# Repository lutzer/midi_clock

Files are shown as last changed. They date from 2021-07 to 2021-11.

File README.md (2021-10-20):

# Midi Clock

## Requirements

* install rust
  * run `curl --proto '=https' --tlsv1.2 -sSf https://sh.rustup.rs | sh` to install rust toolchain
  * use nightly toolchain: `rustup default nightly` (for heap allocator)
  * install target `rustup target install thumbv7m-none-eabi`
  * install cargo-edit `cargo install cargo-edit`, it allows to add dependencies with `cargo add <package>`

* install flash toolchain
  * install stlink on mac with `brew install stlink`
  * install *binutils-arm-none-eabi* with `brew tap PX4/homebrew-px4; brew install gcc-arm-none-eabi`

## Connect Board

* disconnect external power supply
* connect programmer *ST-Link V2* to programming pins of blue pill. Connect pins *SWDIO, GND, SWCLK, and 3.3V and RST to pin R*
* check if programmer is avalaible with `st-info --probe`

## Flash Chip

* run `./flash`
* compile with features with `./flash "feature1,feature2,..."`

## Debugging

* for debugging connect serial adapter, see in [docs/hardware.md](docs/hardware.md)
* flash chip with debug feature: `./flash debug`
* see debugging output with `screen /dev/tty.<adapter> 115200`, (Ctrl+A, K to close monitor)
* for analyzing the timings of the midi clock see [tools/clock_test/README.md](tools/clock_test/README.md)

## Links

* Midi specifications: https://www.midi.org/specifications-old/item/table-1-summary-of-midi-message
* STM32f103 Reference Manual: https://www.st.com//content/ccc/resource/technical/document/reference_manual/59/b9/ba/7f/11/af/43/d5/CD00171190.pdf/files/CD00171190.pdf/jcr:content/translations/en.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
* LCD 0802A: http://www.farnell.com/datasheets/50552.pdf
* Timer registers for stm32f103: https://docs.rs/stm32f1/0.14.0/stm32f1/stm32f103/tim2/index.html

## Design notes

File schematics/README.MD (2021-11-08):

# Midi Clock Schematics

## Setup
* copy libraries from libraries folder to eagle libraries folder
* copy schematics to eagle project folder
* open project
* activate libraries with right click and use in library manager -> use library

## BOM

## PCB Specs

* drill whole sice 0.2mm - 6.3mm
* via size: hole: 0.2mm, copper ring: 0.4mm
* plated hole size: 0.2-6.35
* min clearences
  * hole to hole: 0.5mm
  * via to via: 0.254mm
  * pad to pad with hole: 0.5mm
  * pth to track: 0.33
  * pad to track: 0.2
  * trace width: minimum 0.2mm
  * spacing: 0.2mm

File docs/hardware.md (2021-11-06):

# Hardware

## Bluepill pinout

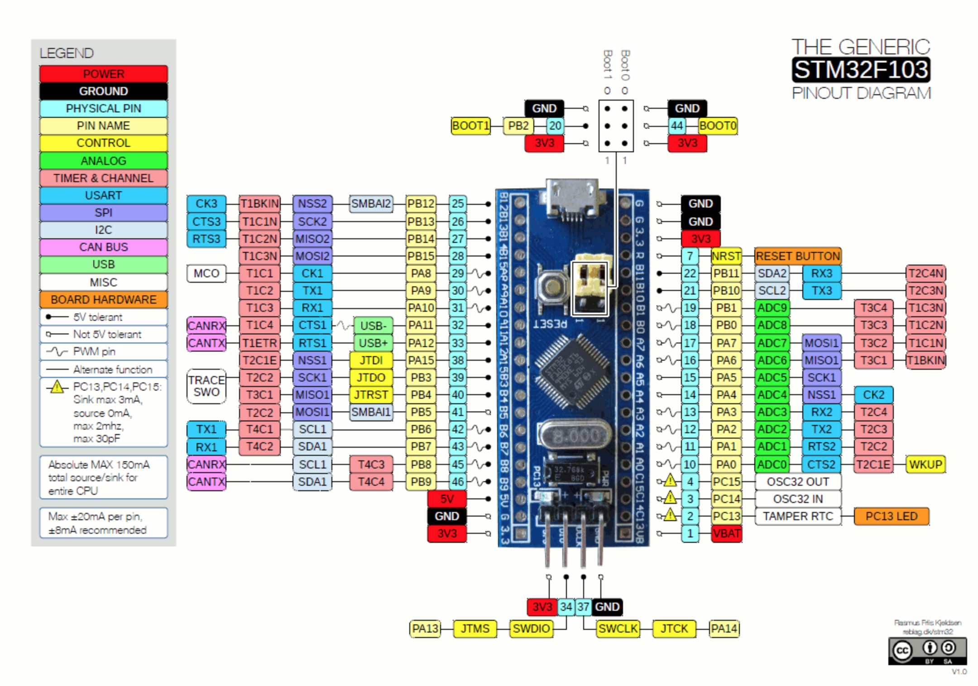
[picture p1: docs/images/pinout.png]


## Connections

| Pin  | Connection |
| ---- | --- |
| PA9  | Debug TX1 / MIDI Out1+2 |
| PA10 | Debug RX1 / MIDI IN |
| PB12 | Button1 		 |
| PB13 | Button2 		 |
| PA7  | Button3 		 |
| PA6  | Button4 (Enc) |
| PA0  | Enc1 |
| PA1  | Enc2 |
| PA9  | MIDI OUT1+2 (Hex Buffer1+2) |
| PB5  | TRIGGER1 (LED MIDI OUT1+2) |
| PA2 | MIDI OUT3+4 (Hex Buffer3+4) |
| PB4  | TRIGGER2 (LED MIDI OUT3+4) |
| PB0  | TRIGGER3 (Hex Buffer5) & LED3 |
| PB1  | TRIGGER4 RESET (Hex Buffer6) & LED4 |
| PA11 | USB D- |
| PA12 | USB D+ |
| PB3 |Clock In|
| PB6 |EEPROM IC SCL|
| PB7 |EEPROM IC SDA|
| PA8 |Display RS|
| PB15 |Display EN|
| PB11 |Display D4|
| PB10 |Display D5|
| PA4 |Display D6|
| PA5 |Display D7|

### Debugging with UART Adapter

Only connect TX to A9, RX to A10 and GND, no need for 3.3V connection

### HD44780 Display

datasheet st7066: https://www.sparkfun.com/datasheets/LCD/st7066.pdf
pinout: https://cdn-reichelt.de/documents/datenblatt/A500/DIPS082E.pdf

### Eeprom

datasheet 24LC64: http://ww1.microchip.com/downloads/en/devicedoc/21189f.pdf

### BOM

* Hex Buffer: 74HC 365
* Clock in: BC 635 Bipolartransistor, NPN, 45V, 1A, 0,8W, TO-92

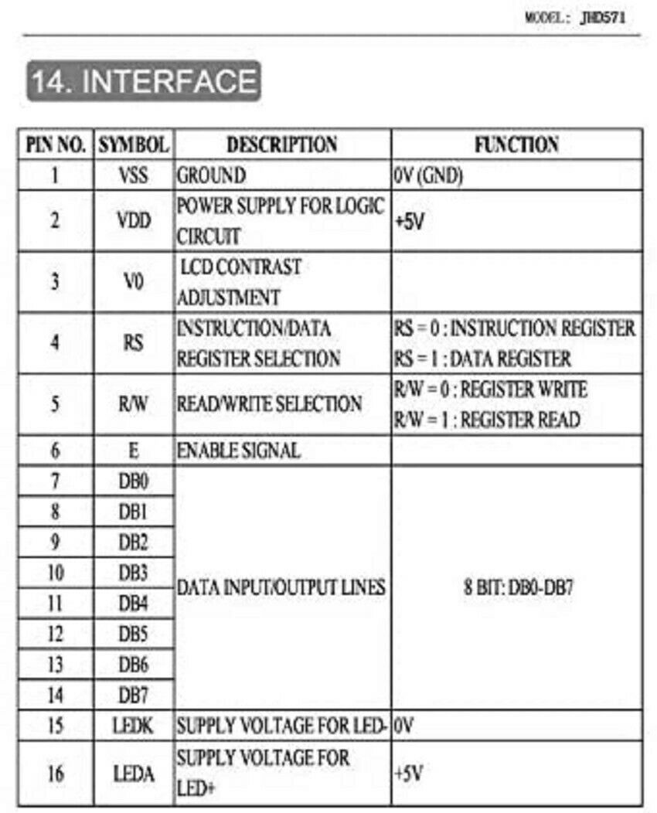
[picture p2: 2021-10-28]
docs/images/lcd_interface.jpeg

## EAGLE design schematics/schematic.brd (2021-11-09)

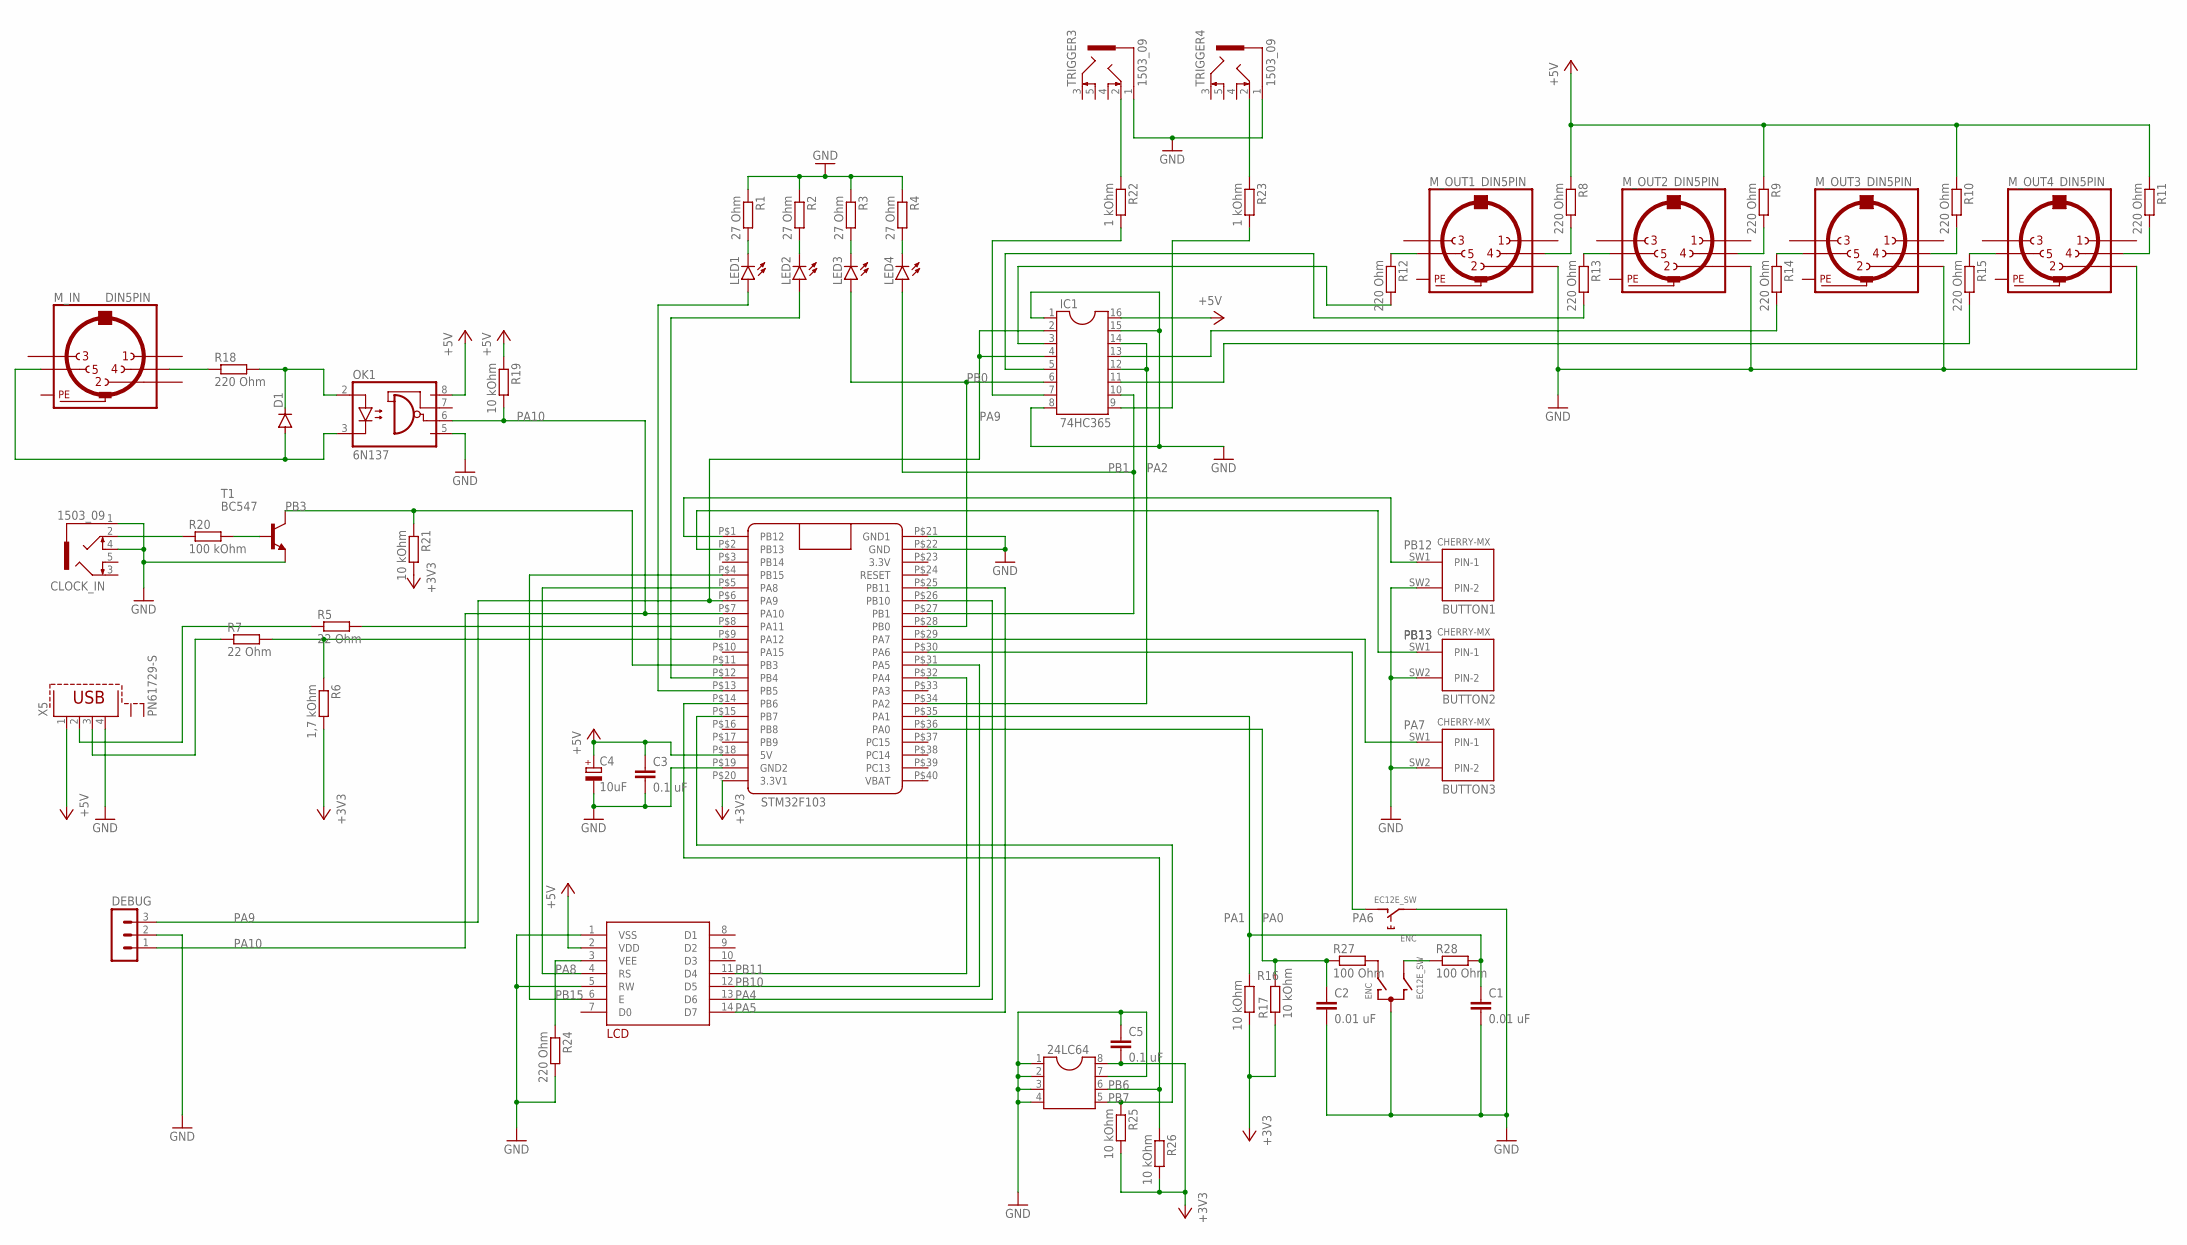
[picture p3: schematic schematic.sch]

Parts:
24LC64: DIL8; DIL08
BUTTON1, BUTTON2, BUTTON3: CHERRY-MX
C1, C2: 0.01 uF; C050-025X075
C3, C5: 0.1 uF; C050-025X075
C4: 10uF; E2,5-6
CLOCK_IN: 1503_09
D1: 1N4446; DO35-10
DEBUG: MA03-1
ENC: EC12E_SW; ALPS_EC12E_SW
IC1: 74HC365; SOCKET-16
LCD: LCD-MODUL2X8
LED1, LED2, LED3, LED4: LED3MM
M_IN: DIN5PIN; MABPM5S
M_OUT1, M_OUT2, M_OUT3, M_OUT4: DIN5PIN; MABPM5S
OK1: 6N137; DIL08
R1, R2, R3, R4: 27 Ohm; 0207/10
R5, R7: 22 Ohm; 0207/10
R6: 1,7 kOhm; 0207/10
R8, R9, R10, R11, R12, R13, R14, R15, R18, R24: 220 Ohm; 0207/10
R16, R17, R19, R21, R25, R26: 10 kOhm; 0207/10
R20: 100 kOhm; 0207/10
R22, R23: 1 kOhm; 0207/10
R27, R28: 100 Ohm; 0207/10
STM32F103: BLUE_PILL
T1: BC547; TO92
TRIGGER3, TRIGGER4: 1503_09
X5: PN61729-S

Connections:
+3V3: 24LC64.8, C5.2, R6.2, R16.2, R17.1, R21.2, R25.2, R26.2, STM32F103.P$20 (3.3V1)
+5V: C3.1, C4.+, IC1.16, LCD.2 (VDD), OK1.8 (VCC), R8.1, R9.1, R10.1, R11.1, R19.1, STM32F103.P$18 (5V), X5.1
GND: 24LC64.1, 24LC64.2, 24LC64.3, 24LC64.4, 24LC64.7, BUTTON1.SW2 (PIN-2), BUTTON2.SW2 (PIN-2), BUTTON3.SW2 (PIN-2), C1.2, C2.2, C3.2, C4.-, C5.1, CLOCK_IN.1, CLOCK_IN.4, DEBUG.2, ENC.C, ENC.E (2), IC1.1, IC1.8, IC1.15, LCD.1 (VSS), LCD.5 (RW), M_OUT1.P2 (2), M_OUT2.P2 (2), M_OUT3.P2 (2), M_OUT4.P2 (2), OK1.5 (GND), R1.1, R2.1, R3.1, R4.1, R24.2, STM32F103.P$19 (GND2), STM32F103.P$21 (GND1), STM32F103.P$22 (GND), T1.1 (E), TRIGGER3.1, TRIGGER4.1, X5.4
unnamed: R5.1, X5.2
unnamed: R5.2, STM32F103.P$8 (PA11)
unnamed: R7.1, X5.3
unnamed: LED1.K (C), R1.2
unnamed: LED2.K (C), R2.2
unnamed: LED3.K (C), R3.2
unnamed: LED4.K (C), R4.2
unnamed: R6.1, R7.2, STM32F103.P$9 (PA12)
unnamed: M_OUT1.P4 (4), R8.2
unnamed: M_OUT2.P4 (4), R9.2
unnamed: M_OUT3.P4 (4), R10.2
unnamed: M_OUT4.P4 (4), R11.2
unnamed: M_OUT1.P5 (5), R12.1
unnamed: M_OUT2.P5 (5), R13.1
unnamed: M_OUT3.P5 (5), R14.1
unnamed: M_OUT4.P5 (5), R15.1
unnamed: IC1.3, R12.2
unnamed: IC1.5, R13.2
unnamed: IC1.13, R14.2
unnamed: IC1.11, R15.2
unnamed: ENC.A, R27.2
unnamed: ENC.B, R28.1
unnamed: D1.C, OK1.2 (A), R18.2
unnamed: D1.A, M_IN.P5 (5), OK1.3 (C)
unnamed: M_IN.P4 (4), R18.1
unnamed: LCD.3 (VEE), R24.1
unnamed: CLOCK_IN.2, R20.1
unnamed: R20.2, T1.2 (B)
unnamed: R22.1, TRIGGER3.2
unnamed: IC1.7, R22.2
unnamed: R23.1, TRIGGER4.2
unnamed: IC1.9, R23.2
PA0: C2.1, R17.2, R27.1, STM32F103.P$36 (PA0)
PA1: C1.1, R16.1, R28.2, STM32F103.P$35 (PA1)
PA2: IC1.12, IC1.14, STM32F103.P$34 (PA2)
PA4: LCD.11 (D4), STM32F103.P$32 (PA4)
PA5: LCD.12 (D5), STM32F103.P$31 (PA5)
PA6: ENC.D (1), STM32F103.P$30 (PA6)
PA7: BUTTON3.SW1 (PIN-1), STM32F103.P$29 (PA7)
PA8: LCD.4 (RS), STM32F103.P$5 (PA8)
PA9: DEBUG.3, IC1.2, IC1.4, STM32F103.P$6 (PA9)
PA10: DEBUG.1, OK1.6 (VO), R19.2, STM32F103.P$7 (PA10)
PB0: IC1.6, LED3.A, STM32F103.P$28 (PB0)
PB1: IC1.10, LED4.A, STM32F103.P$27 (PB1)
PB3: R21.1, STM32F103.P$11 (PB3), T1.3 (C)
PB4: LED2.A, STM32F103.P$12 (PB4)
PB5: LED1.A, STM32F103.P$13 (PB5)
PB6: 24LC64.6, R26.1, STM32F103.P$14 (PB6)
PB7: 24LC64.5, R25.1, STM32F103.P$15 (PB7)
PB10: LCD.13 (D6), STM32F103.P$26 (PB10)
PB11: LCD.14 (D7), STM32F103.P$25 (PB11)
PB12: BUTTON1.SW1 (PIN-1), STM32F103.P$1 (PB12)
PB13: BUTTON2.SW1 (PIN-1), STM32F103.P$2 (PB13)
PB15: LCD.6 (E), STM32F103.P$4 (PB15)
PE: M_IN.PE, M_IN.PE@ (PE), M_OUT1.PE, M_OUT1.PE@ (PE), M_OUT2.PE, M_OUT2.PE@ (PE), M_OUT3.PE, M_OUT3.PE@ (PE), M_OUT4.PE, M_OUT4.PE@ (PE)

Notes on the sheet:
STM32F103

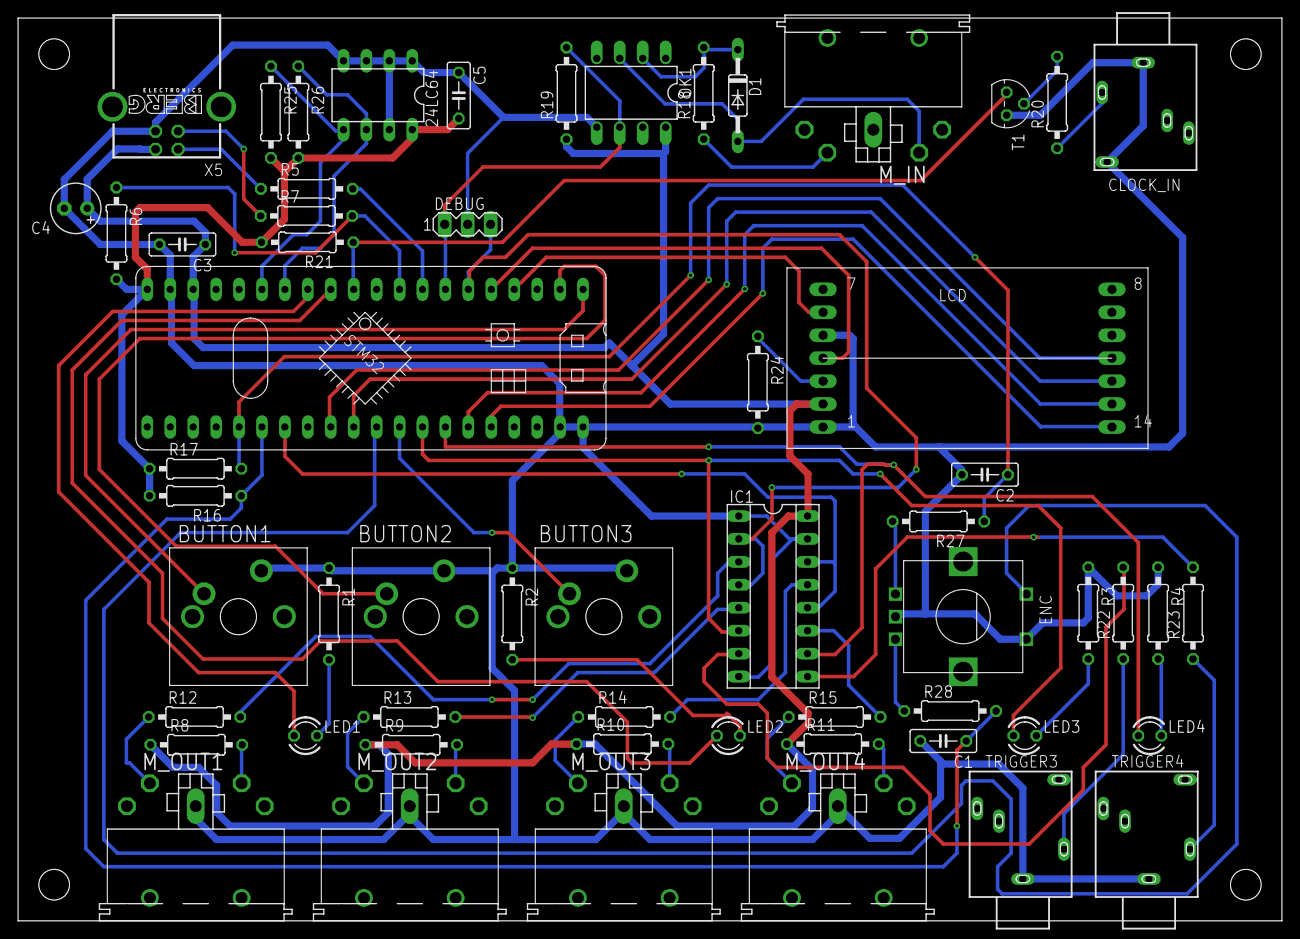
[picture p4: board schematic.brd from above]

Board: 2 copper layers, 140.0 x 100.0 mm, 58 parts (0 on the bottom side), 58 nets.

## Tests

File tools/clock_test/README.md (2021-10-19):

# Clock Analyzer

* upload clock_analyzer firmware on arduino uno
* connect the Rx port of the arduino with the Tx of the midi signal you want to analyze
* flash midi clock with `./flash clock_test`
* set serial port of arduino in *clock_analyzer.py* and run python script with: `python3 clock_analyzer.py`

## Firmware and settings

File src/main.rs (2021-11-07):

#![no_std]
#![no_main]

use cortex_m_rt::entry;
use cortex_m::interrupt;
use cortex_m::interrupt::{CriticalSection};

use core::panic::PanicInfo;

mod peripherals;
use peripherals::{Peripherals};

mod serial;
use serial::{SerialWriter};

mod buttons;
use buttons::{Buttons, BUTTON1_MASK, BUTTON2_MASK, BUTTON3_MASK, BUTTON4_MASK, buttons_on_timer_tick};

mod timers;
use timers::{Timer3};

mod debug;

mod utils;

mod encoder;
use encoder::{Encoder};

mod clock;
use clock::{Clock};

mod triggers;
use triggers::{Triggers, TRIGGER4_MASK};

mod statemachine;
use statemachine::{Statemachine, State, RunState};

mod context;
use context::{Context, CONTEXT};

mod display;
use display::{Display};

mod midi;
use midi::{MidiMessage};

mod st7066;

mod eeprom;
use eeprom::{Eeprom};

mod memory;
use memory::{Memory};

fn on_button_press(statemachine: &mut Statemachine, changes: u8, state: u8) {
  if (changes & BUTTON1_MASK) > 0 {
    statemachine.button1_pressed(changes & BUTTON1_MASK & state > 0);
  }
  if (changes & BUTTON2_MASK) > 0 {
    statemachine.button2_pressed(changes & BUTTON2_MASK & state > 0);
  }
  if (changes & BUTTON3_MASK) > 0 {
    statemachine.button3_pressed(changes & BUTTON3_MASK & state > 0);
  }
  if (changes & BUTTON4_MASK) > 0 {
    statemachine.encoder_pressed(changes & BUTTON4_MASK & state > 0);
  }
}

fn on_encoder_change(statemachine: &mut Statemachine, rotation: i16) {
  statemachine.encoder_turn(rotation);
}

fn on_state_change(state: &State, clock: &mut Clock, display: &mut Display) {
  static mut PREV_STATE : Option<State> = None;

  debug!("state change");
  debug!(*state);

  if let Some(prev_state) = unsafe { PREV_STATE } {
    // check for state changes
    if prev_state.running != state.running {
      clock.set_runstate(state.running);
      send_midi_ctrl_msg(state.running);
    }
    if prev_state.bpm != state.bpm {
      clock.set_bpm(state.bpm);
    }
    if prev_state.clock_trigger_multiplier != state.clock_trigger_multiplier {
      clock.set_trigger_multiplier(state.clock_trigger_multiplier);
    }
    if prev_state.clock_divisions[0] != state.clock_divisions[0] || prev_state.clock_divisions[1] != state.clock_divisions[1] {
      clock.set_divisions(state.clock_divisions);
    }
    if prev_state.clock_bar_length != state.clock_bar_length {
      clock.set_bar_length(state.clock_bar_length);
    } 
    if prev_state.clock_sync != state.clock_sync {
      clock.sync(state.clock_sync);
    }
    display.update(state);
  }
  unsafe { PREV_STATE = Some(*state) }
}

fn send_midi_ctrl_msg(current: RunState) {
  interrupt::free(|cs| {
    Context::get_instance(cs, &|ctx| {
      match current {
        RunState::RUNNING => { 
          ctx.serial.write(2, MidiMessage::Continue as u8).ok(); 
        },
        RunState::PAUSED => { 
          ctx.serial.write(2, MidiMessage::Stop as u8).ok(); 
        },
        RunState::STOPPING => { 
          ctx.serial.write(2, MidiMessage::Stop as u8).ok(); 
        },
        RunState::STOPPED => { 
          ctx.serial.write(2, MidiMessage::Start as u8).ok();
          ctx.triggers.fire(TRIGGER4_MASK); // send sync reset trigger
        }
      }
    });
  });
}

#[entry]
fn main() -> ! {

  // initialize peripherals
  let peripherals = Peripherals::init();

  // init eeprom memory chip
  let mut memory = Memory::new(Eeprom::new(peripherals.i2c1.unwrap()));

  // initialize statemachine and read state from memory
  let mut statemachine = Statemachine::new(memory.load_state());
  let initial_state = statemachine.get_state();

  // initializes all buttons and sets debounce timer
  let buttons = Buttons::new(peripherals.button1.unwrap(), peripherals.button2.unwrap(), 
    peripherals.button3.unwrap(), peripherals.button4.unwrap());
  Timer3::add_handler(0, buttons_on_timer_tick);

  // initialize clock, sends triggers and MIDI CLOCK msgs in regular intervals
  let mut clock = Clock::new(&initial_state);
  
  // initialize rotary encoder
  let encoder = Encoder::new();

  // create global context to share peripherals among interrupts
  {
    let triggers = Triggers::new(
      peripherals.trigger1.unwrap(), 
      peripherals.trigger2.unwrap(),
      peripherals.trigger3.unwrap(),
      peripherals.trigger4.unwrap()
    );
    Timer3::add_handler(2, Triggers::on_timer_tick);
    let serial = SerialWriter::new(peripherals.usart1.unwrap(), peripherals.usart2.unwrap());
    
    interrupt::free(|cs| {
      let context = Context { triggers: triggers, serial: serial };
      CONTEXT.borrow(cs).replace(Some(context));
    });
  }

  // setup display
  let mut display = Display::new(peripherals.display.unwrap(), peripherals.delay.unwrap());
  Timer3::add_handler(1, Display::on_timer_tick);
  display.init();
  display.update(&initial_state);

  debug!("start");
  
  // main loop
  loop {
    buttons.on_change().map(|(changes, reading)| {
      on_button_press(&mut statemachine, changes, reading);
    });
    encoder.on_change().map(|rotation| {
      on_encoder_change(&mut statemachine, rotation);
    });
    statemachine.on_change().map(|state| {
      on_state_change(&state, &mut clock, &mut display);
      // memory.write_state(&state).ok();
    });
    display.render();
  }
}

// Call this function when panic occurs
#[panic_handler]
fn panic(info: &PanicInfo) -> ! {
  debug!("PANIC");
  if let Some(s) = info.payload().downcast_ref::<&str>() {
    debug!(*s);
  }
  
  loop {}
}

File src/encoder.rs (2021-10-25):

use stm32f1xx_hal::{
  pac::{interrupt},
  gpio,
  gpio::ExtiPin,
  gpio::Edge,
  afio,
  pac
};

use core::sync::atomic::{AtomicI32, Ordering};

use cortex_m::interrupt::{Mutex};
use core::cell::{RefCell};

use embedded_hal::digital::v2::InputPin;

#[derive(Copy,Clone)]
enum EncoderState {
  CwStart = 0x01,
  CwStep1 = 0x02,
  CwStep2 = 0x03,
  CwFinal = 0x10,

  CcwStart = 0x04,
  CcwStep1 = 0x05,
  CcwStep2 = 0x06,
  CcwFinal = 0x20,

  Undefined = 0x40,
}

const TRANSITION_LOOKUPTABLE: [[EncoderState; 4]; 7] = [
  [ EncoderState::Undefined, EncoderState::CcwStart, EncoderState::CwStart, EncoderState::Undefined ],  // init state -> 1,2

  [ EncoderState::Undefined, EncoderState::Undefined, EncoderState::Undefined, EncoderState::CwStep1 ], // cw start -> 3
  [ EncoderState::Undefined, EncoderState::CwStep2, EncoderState::CwStart, EncoderState::Undefined ], // cw step1 -> 1, <- 2
  [ EncoderState::CwFinal, EncoderState::CwStep2, EncoderState::Undefined, EncoderState::CwStep1 ], // cw step2 -> 0, <- 2

  [ EncoderState::Undefined, EncoderState::Undefined, EncoderState::Undefined, EncoderState::CcwStep1 ], // ccw start -> 3
  [ EncoderState::Undefined, EncoderState::Undefined, EncoderState::CcwStep2, EncoderState::Undefined ], // ccw step1 -> 2, <- 0
  [ EncoderState::CcwFinal, EncoderState::Undefined, EncoderState::Undefined , EncoderState::Undefined ] // ccw step2 -> 0, <- 2
];

fn get_transition(state: u8, transition: u8) -> EncoderState {
  return TRANSITION_LOOKUPTABLE[state as usize][transition as usize];
}

const MAX_I32_HALF: i32 = i32::MAX / 2;

static ENCODER_POSITION: AtomicI32 = AtomicI32::new(0);

pub struct Encoder {}

type EncoderPin1Type = stm32f1xx_hal::gpio::gpioa::PA0<gpio::Input<gpio::PullUp>>;
type EncoderPin2Type = stm32f1xx_hal::gpio::gpioa::PA1<gpio::Input<gpio::PullUp>>;

static ENCODER_PIN1: Mutex<RefCell<Option<EncoderPin1Type>>> =
  Mutex::new(RefCell::new(None));

static ENCODER_PIN2: Mutex<RefCell<Option<EncoderPin2Type>>> =
  Mutex::new(RefCell::new(None));

impl Encoder {

  pub fn init(
    exti: &stm32f1xx_hal::pac::EXTI, 
    pa0: gpio::gpioa::PA0<gpio::Input<gpio::Floating>>,
    pa1: gpio::gpioa::PA1<gpio::Input<gpio::Floating>>,
    crl: &mut gpio::gpioa::CRL,
    afio: &mut afio::Parts,
  ) {
    // enable interrupt for pin pa0
    let mut enc_pin1 = pa0.into_pull_up_input(crl);
    enc_pin1.make_interrupt_source(afio);
    enc_pin1.trigger_on_edge(exti, Edge::RISING_FALLING);
    enc_pin1.enable_interrupt(exti);
    cortex_m::interrupt::free(|cs| ENCODER_PIN1.borrow(cs).replace(Some(enc_pin1)));

    // enable interrupt for pin pa1
    let mut enc_pin2 = pa1.into_pull_up_input(crl);
    enc_pin2.make_interrupt_source(afio);
    enc_pin2.trigger_on_edge(exti, Edge::RISING_FALLING);
    enc_pin2.enable_interrupt(exti);
    cortex_m::interrupt::free(|cs| ENCODER_PIN2.borrow(cs).replace(Some(enc_pin2)));

    unsafe {
      pac::NVIC::unmask(pac::Interrupt::EXTI0);
      pac::NVIC::unmask(pac::Interrupt::EXTI1);
    }
  }


  pub fn new() -> Encoder {
    return Encoder {};
  }

  pub fn on_change(&self) -> Option<i16> {
    static mut LAST_POSITION : i32 = 0;

    let position = ENCODER_POSITION.load(Ordering::Relaxed);
    
    // calculate the difference between last read position and current position
    unsafe {
      let delta = position - LAST_POSITION;

      // reset position when position is out of bounds
      if i32::abs(delta) > MAX_I32_HALF {
        LAST_POSITION = 0;
        ENCODER_POSITION.store(0, Ordering::Relaxed);
      // else call handler function
      } else if delta != 0 {
        LAST_POSITION = position;
        return Some(delta as i16);
      }
    }
    return None;
  }
}

unsafe fn on_interrupt(pin1: Option<bool>, pin2: Option<bool>) {
  static mut STATE: EncoderState = EncoderState::Undefined;
  static mut READING: u8 = 0;

  pin1.map(|r| {
    READING &= !0b01;
    READING |= r as u8;
  });

  pin2.map(|r| {
    READING &= !0b10;
    READING |= (r as u8) << 1;
  });

  STATE = get_transition((STATE as u8) & 0x0F, READING);
  
  if STATE as u8 == EncoderState::CwFinal as u8 {
    ENCODER_POSITION.fetch_add(1, Ordering::Relaxed);
  } else if STATE as u8 == EncoderState::CcwFinal as u8 {
    ENCODER_POSITION.fetch_add(-1, Ordering::Relaxed);
  }
}

// interrupt for pin1
#[interrupt]
unsafe fn EXTI0() {
  cortex_m::interrupt::free(|cs|  {
    let mut enc_pin1 = ENCODER_PIN1.borrow(cs).borrow_mut();
    on_interrupt(Some(enc_pin1.as_ref().unwrap().is_low().unwrap()), None);
    enc_pin1.as_mut().unwrap().clear_interrupt_pending_bit();
  });
}

// interrupt for pin2
#[interrupt]
unsafe fn EXTI1() {
  cortex_m::interrupt::free(|cs|  {
    let mut enc_pin2 = ENCODER_PIN2.borrow(cs).borrow_mut();
    on_interrupt(None, Some(enc_pin2.as_ref().unwrap().is_low().unwrap()));
    enc_pin2.as_mut().unwrap().clear_interrupt_pending_bit();
  });
}

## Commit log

2021-07-30 correction in flash script
    [main.rs]
2021-08-26 added initial button struct
2021-08-27 added timer handler struct
2021-08-30 added timer2 handlers
2021-09-01 timer is working now, added debug class
2021-09-02 fixed timer2 struct
2021-09-05 added button handler
2021-09-15 added 3 button debounce
2021-09-16 added interrupt detection for encoder
2021-09-16 added encoder interrupt handler
2021-09-27 changed clock timer
2021-09-27 fixed encoder interrupts
2021-10-01 refactored some timer functions, cleaned up debugging methods
2021-10-03 removed jitter from timer
2021-10-04 added additinal jitter tests
    [main.rs, peripherals.rs, timers.rs]
2021-10-06 swapped timer2 with timer3
    [clock.rs, main.rs, timers.rs]
2021-10-20 changed clock timer to use overflow counter
2021-10-23 added spi display
2021-10-27 added schematic
    [schematic.sch]
2021-10-27 added eeprom chip to schematic
    [schematic.sch]
2021-10-28 added lcd8x2 display
    [schematic.sch]
2021-11-05 updated timings
    [schematic.sch]
2021-11-07 updated schematic
    [schematic.sch]
2021-11-07 added footprints, started brd
    [schematic.brd, schematic.sch]
2021-11-08 finished first version of schematic;
    [schematic.brd, schematic.sch]
2021-11-09 fixed circuit errors
    [schematic.brd]
2021-11-09 fixed some schematic errors
    [schematic.brd, schematic.sch]
2021-11-09 final pcb design v1.0
    [schematic.brd, schematic.sch]
